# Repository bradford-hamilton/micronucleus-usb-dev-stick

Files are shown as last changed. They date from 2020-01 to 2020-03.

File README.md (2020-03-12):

First go at building a usb development board using the [ATtiny85](https://www.microchip.com/wwwproducts/en/ATtiny85). I took a [digispark](http://digistump.com/products/1) schematic, modified it to use a [USB Male Type A Connector](https://www.sparkfun.com/products/437), two 1kΩ resistors (where they were blank), placed components on a relatively small footprint, and set up the traces.

The ATtiny85 must be flashed with [micronucleus](https://github.com/micronucleus/micronucleus) (occupies 2kB out of the 8kB flash) to have the ability to be compatible with Arduino's IDE (specifically to be used as a Digispark board). Micronucleus implements [V-USB](https://www.obdev.at/products/vusb/index.html) which is a software-only implementation of a low-speed USB device. Created on [Eagle](https://www.autodesk.com/products/eagle/free-download). Project includes board (.brd), schematic (.sch), a BOM, and all gerber & drill files.

## Status:
- First order came in! Came with some pins pre-soldered, but pins weren't in the order at all :( Need to de-solder to 3D-print a slimmer case as had planned.
- Didn't come with the [USB male type A connectors](https://www.sparkfun.com/products/437)). Will have to order some more separately.
- Waiting on one more shipment of what are basically digispark clones
- ~~Just ordered a handful of the "Board with pins v1" off [PCBWay](https://www.pcbway.com). Will update if they work!~~

___

#### v1 prototype shipped 3/11 front
board

#### v1 prototype shipped 3/11 back
board

___

#### Board with pins v1
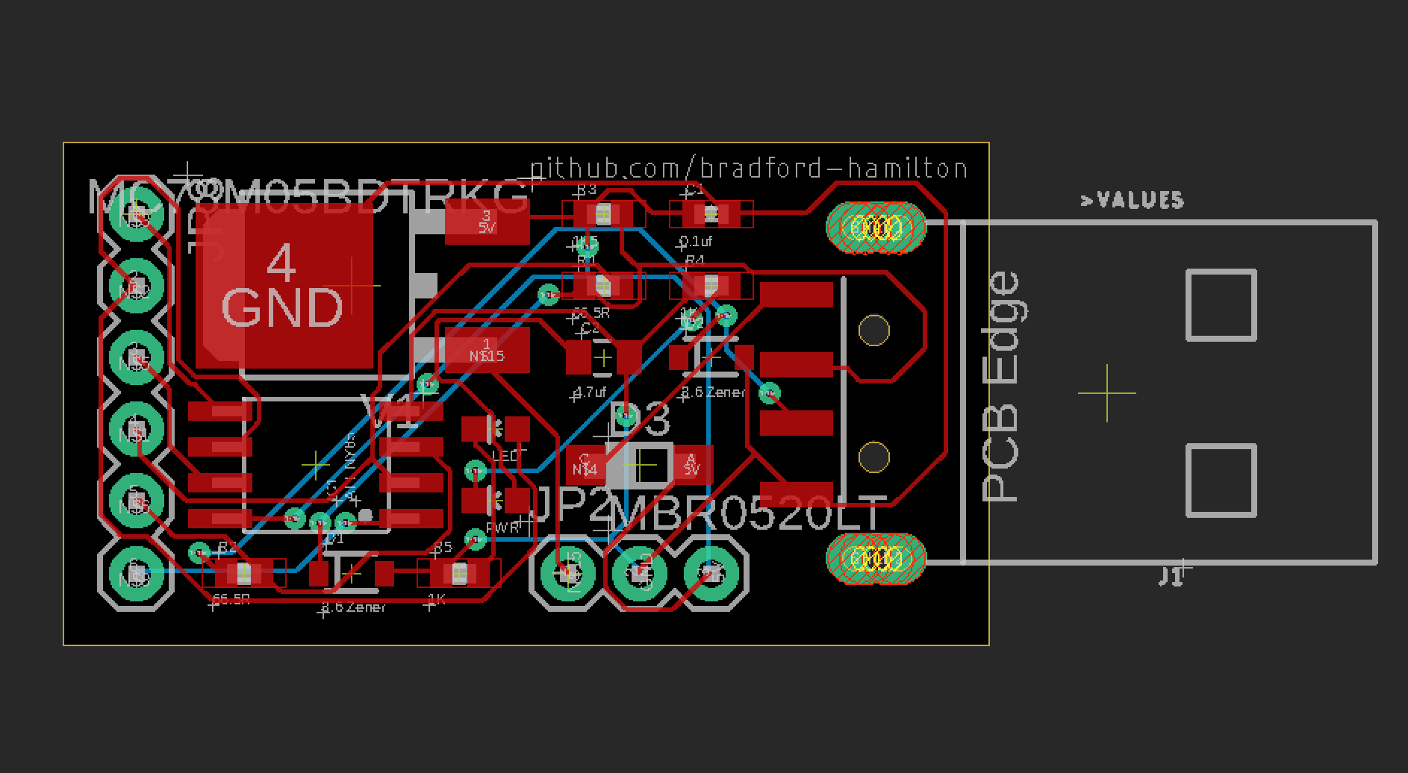
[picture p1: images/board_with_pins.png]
board


#### Schematic with pins v1
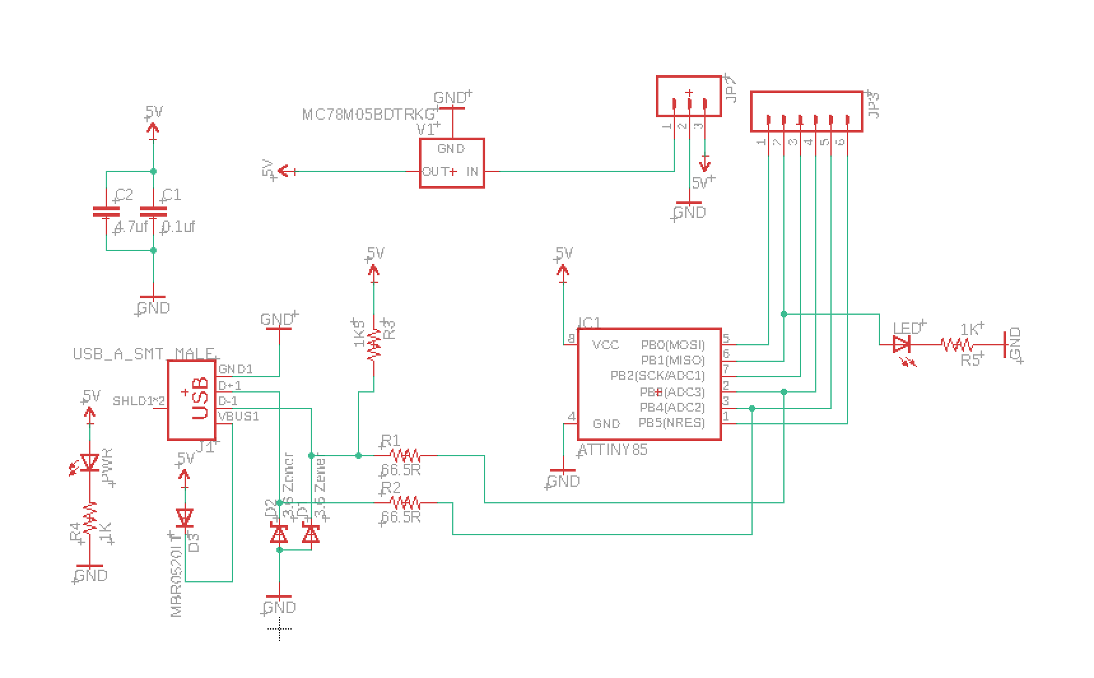
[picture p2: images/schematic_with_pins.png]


___

#### Board without pins v1
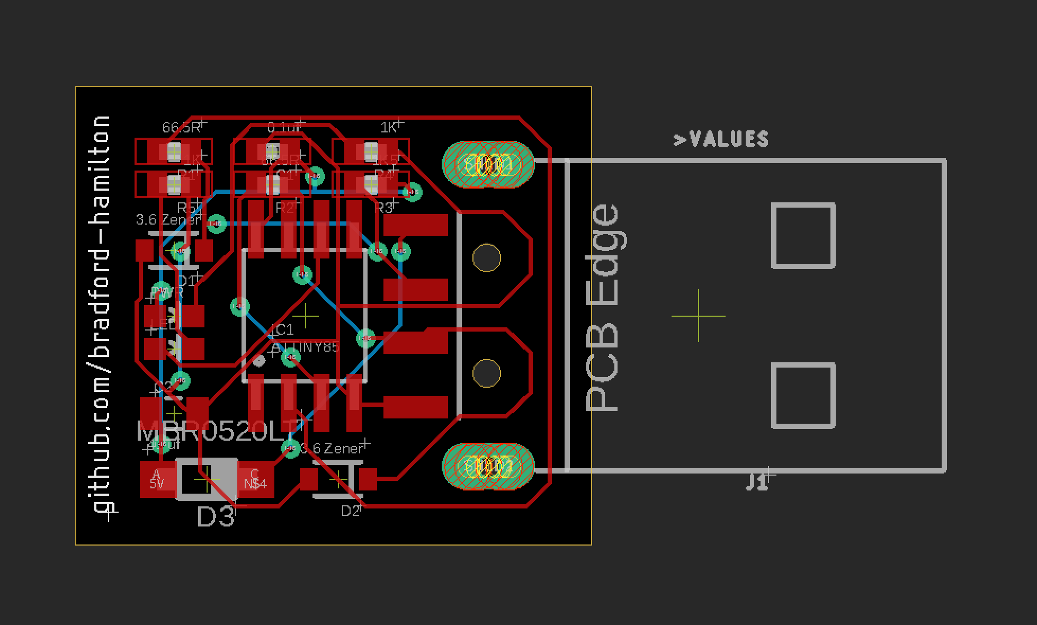
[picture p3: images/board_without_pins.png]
board


#### Schematic without pins v1
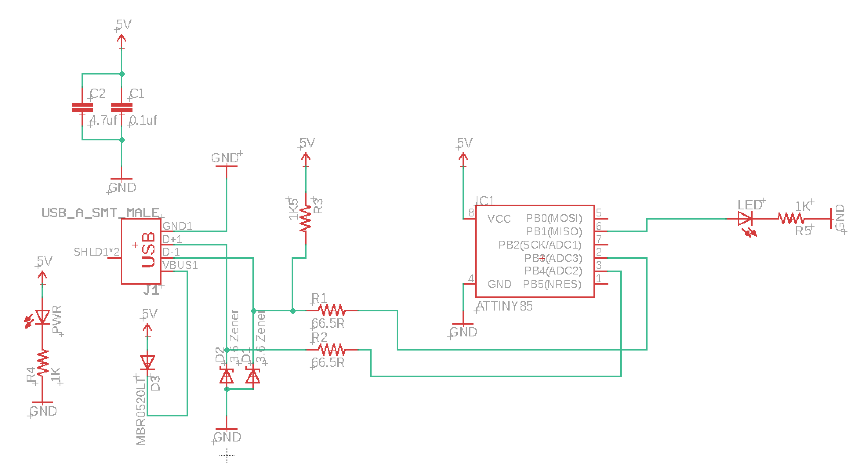
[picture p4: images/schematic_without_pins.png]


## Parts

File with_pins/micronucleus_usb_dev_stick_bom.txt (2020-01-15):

Partlist exported from /Users/bradford/Downloads/digispark_full_custom/digispark_full_custom.sch at 1/14/20 4:09 PM

Qty Value          Device            Package        Parts    Description                                        PROD_ID   
2                  LED0603           LED-0603       LED, PWR LEDs                                                         
1                  M03PTH            1X03           JP2      Header 3                                                     
1                  M06SIP            1X06           JP3      Header 6                                                     
1   0.1uf          CAP0402-CAP       0402-CAP       C1       Capacitor                                                    
2   1K             RESISTOR0402-RES  0402-RES       R4, R5   Resistor                                                     
1   1K5            RESISTOR0402-RES  0402-RES       R3       Resistor                                                     
2   3.6 Zener      DIODE-ZENER-BZT52 SOD-323        D1, D2   part# BZT52C3V6-HE3-08                                                  
1   4.7uf          CAP0805           0805           C2       Capacitor                                                    
2   66.5R          RESISTOR0402-RES  0402-RES       R1, R2   Resistor                                                     
1   ATTINY85       ATTINY85          SO08-EIAJ      IC1      Atmel ATTiny85                                               
1   MBR0520LT      MBR0520LT         SOD123         D3       SCHOTTKY BARRIER RECTIFIER                                   
1   MC78M05BDTRKG  LP2950CDT-3.0     DPACK          V1       Source: http://cache.national.com/ds/LP/LP2950.pdf           
1   USB_A_SMT_MALE USB_A_SMT_MALE    USB-A-SMT-MALE J1       https://www.sparkfun.com/products/437              CONN-11499

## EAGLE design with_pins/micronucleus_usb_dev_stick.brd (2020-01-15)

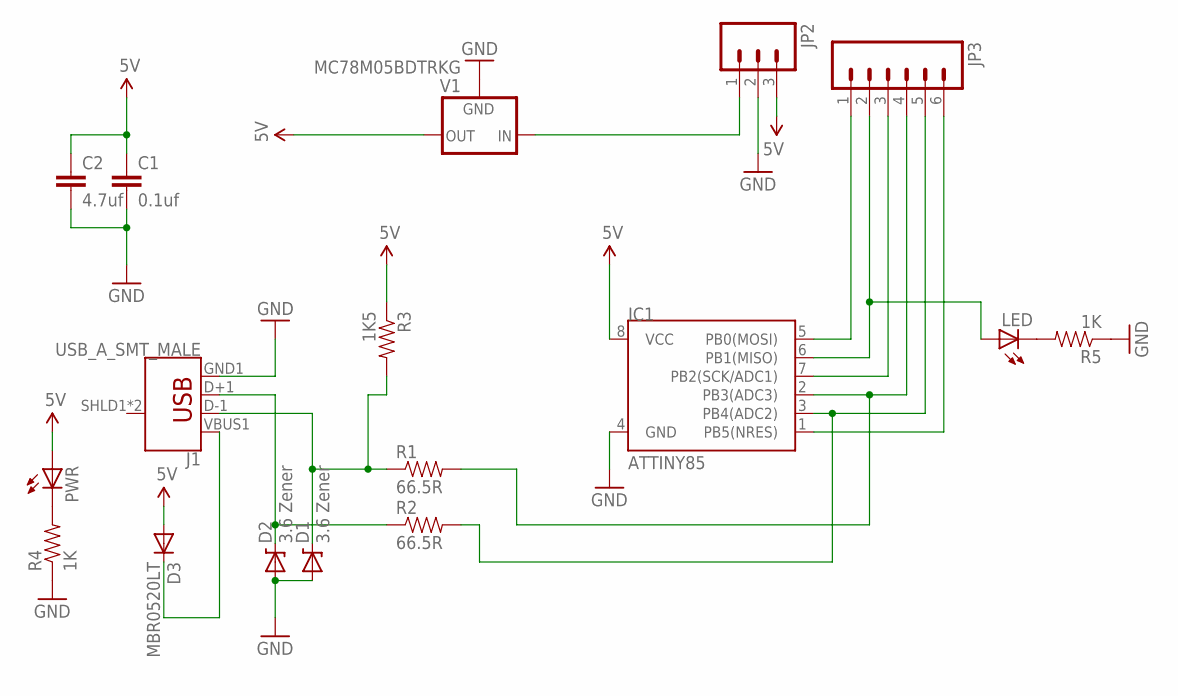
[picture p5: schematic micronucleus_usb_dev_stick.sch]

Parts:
C1: 0.1uf; 0402-CAP
C2: 4.7uf; 0805
D1, D2: 3.6 Zener; SOD-323
D3: MBR0520LT; SOD123
IC1: ATTINY85; SO08-EIAJ
J1: USB_A_SMT_MALE; USB-A-SMT-MALE
JP2: M03PTH; 1X03
JP3: M06SIP; 1X06
LED: LED0603; LED-0603
PWR: LED0603; LED-0603
R1, R2: 66.5R; 0402-RES
R3: 1K5; 0402-RES
R4, R5: 1K; 0402-RES
V1: MC78M05BDTRKG; DPACK

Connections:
5V: C1.1, C2.1, D3.A, IC1.8 (VCC), JP2.3, PWR.A, R3.1, V1.3 (OUT)
GND: C1.2, C2.2, D1.2 (A), D2.2 (A), IC1.4 (GND), J1.GND1 (GND), JP2.2, R4.1, R5.1, V1.4 (GND)
unnamed: IC1.2 (PB3(ADC3)), JP3.4, R1.2
unnamed: IC1.6 (PB1(MISO)), JP3.2, LED.A
unnamed: IC1.5 (PB0(MOSI)), JP3.1
unnamed: D3.C, J1.VBUS1 (VBUS)
unnamed: IC1.7 (PB2(SCK/ADC1)), JP3.3
unnamed: IC1.3 (PB4(ADC2)), JP3.5, R2.2
unnamed: IC1.1 (PB5(NRES)), JP3.6
unnamed: D1.1 (C), J1.D-1 (D-), R1.1, R3.2
unnamed: D2.1 (C), J1.D+1 (D+), R2.1
unnamed: LED.C, R5.2
unnamed: JP2.1, V1.1 (IN)
unnamed: PWR.C, R4.2

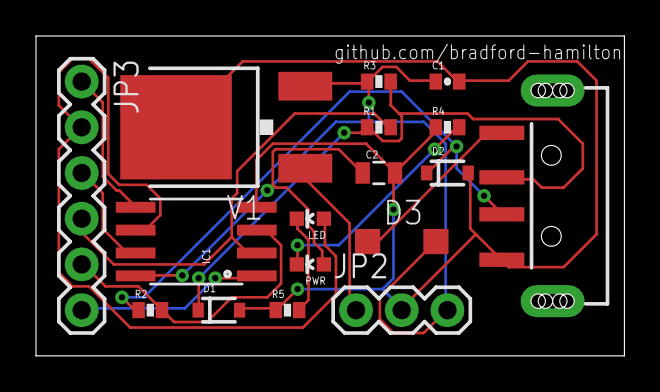
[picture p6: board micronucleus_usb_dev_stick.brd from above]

Board: 2 copper layers, 32.7 x 17.8 mm, 17 parts (0 on the bottom side), 14 nets.

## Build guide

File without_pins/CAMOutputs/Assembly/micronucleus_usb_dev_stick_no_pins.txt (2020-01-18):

Partlist exported from /Users/bradford/Downloads/micronucleus_usb_dev_stick_no_pins/micronucleus_usb_dev_stick_no_pins.sch at 1/17/20 5:32 PM

Qty Value          Device            Package        Parts    Description                PROD_ID   
2                  LED0603           LED-0603       LED, PWR LEDs                                 
1   0.1uf          CAP0402-CAP       0402-CAP       C1       Capacitor                            
2   1K             RESISTOR0402-RES  0402-RES       R4, R5   Resistor                             
1   1K5            RESISTOR0402-RES  0402-RES       R3       Resistor                             
2   3.6 Zener      DIODE-ZENER-BZT52 SOD-323        D1, D2   Zener Diode                          
1   4.7uf          CAP0805           0805           C2       Capacitor                            
2   66.5R          RESISTOR0402-RES  0402-RES       R1, R2   Resistor                             
1   ATTINY85       ATTINY45          SO08-EIAJ      IC1      Atmel ATTiny45                       
1   MBR0520LT      MBR0520LT         SOD123         D3       SCHOTTKY BARRIER RECTIFIER           
1   USB_A_SMT_MALE USB_A_SMT_MALE    USB-A-SMT-MALE J1       USB-A Connector            CONN-11499

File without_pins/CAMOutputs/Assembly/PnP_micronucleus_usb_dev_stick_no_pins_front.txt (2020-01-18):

C1	24.13	16.51	180.00	0.1uf	0402-CAP
C2	20.32	6.35	0.00	4.7uf	0805
D1	20.32	12.70	180.00	3.6 Zener	SOD-323
D2	26.67	3.81	180.00	3.6 Zener	SOD-323
D3	21.59	3.81	180.00	MBR0520LT	SOD123
IC1	25.40	10.15	0.00	ATTINY85	SO08-EIAJ
J1	29.69	10.13	180.00	USB_A_SMT_MALE	USB-A-SMT-MALE
LED	20.32	8.89	270.00		LED-0603
PWR	20.32	10.16	270.00		LED-0603
R1	20.32	16.51	180.00	66.5R	0402-RES
R2	24.13	15.24	180.00	66.5R	0402-RES
R3	27.94	15.24	180.00	1K5	0402-RES
R4	27.94	16.51	180.00	1K	0402-RES
R5	20.32	15.24	180.00	1K	0402-RES

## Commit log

2020-01-15 Add cam outputs from eagle
    [copper_bottom.gbr, copper_top.gbr, drill_1_16.xln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]
2020-01-15 Add board and schematic files
    [micronucleus_usb_dev_stick.brd, micronucleus_usb_dev_stick.sch]
2020-01-15 update bill of materials
2020-01-18 Update repo to contain a micronucleus dev stick with and without pins and all their corresponding files
    [micronucleus_usb_dev_stick.brd, micronucleus_usb_dev_stick.sch, micronucleus_usb_dev_stick_no_pins.brd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]
2020-03-12 add some images and readme updates around first board shipment

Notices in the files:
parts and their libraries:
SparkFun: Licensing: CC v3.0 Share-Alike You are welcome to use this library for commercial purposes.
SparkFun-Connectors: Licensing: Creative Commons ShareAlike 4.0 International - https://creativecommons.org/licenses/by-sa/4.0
